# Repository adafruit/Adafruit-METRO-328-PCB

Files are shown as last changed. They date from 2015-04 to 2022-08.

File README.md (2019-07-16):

## Adafruit METRO 328 PCB

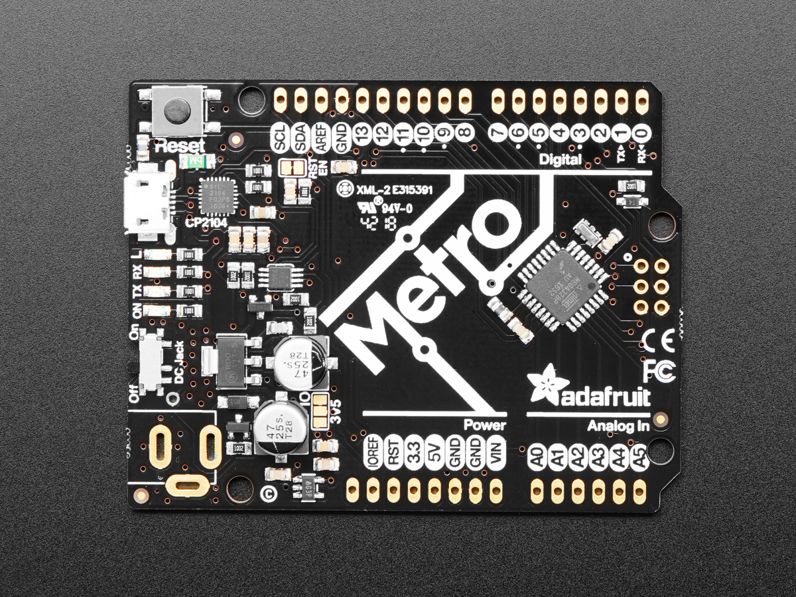
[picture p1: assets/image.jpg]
<a href="http://www.adafruit.com/products/2466"><br/>
Click here to purchase one from the Adafruit shop</a>

PCB files for the Adafruit METRO 328. Format is EagleCAD schematic and board layout

For more details, check out the product page at
* https://www.adafruit.com/products/2466

### Description

We sure love the ATmega328 here at Adafruit, and we use them a lot for our own projects. The processor has plenty of GPIO, Analog inputs, hardware UART SPI and I2C, timers and PWM galore - just enough for most simple projects. When we need to go small, we use a Metro Mini, but when size isn't as much of a concern, and a USB-serial converter is required, we reach for an Adafruit METRO.

METRO is the culmination of years of playing with AVRs: we wanted to make a development board that is easy to use and is hacker friendly.

ATmega328 brains - This popular chip has 32KB of flash (1/2 K is reserved for the bootloader), 2KB of RAM, clocked at 16MHz
Power the METRO with 7-9V polarity protected DC or the micro USB connector to any 5V USB source. The 2.1mm DC jack has an on/off switch next to it so you can turn off your setup easily. The METRO will automagically switch between USB and DC.
METRO has 20 GPIO pins, 6 of which are Analog in as well, and 2 of which are reserved for the USB-serial converter. There's also 6 PWMs available on 3 timers (1 x 16-bit, 2 x 8-bit). There's a hardware SPI port, hardware I2C port and hardware UART to USB.
GPIO Logic level is 5V but by cutting and soldering closed a jumper, you can easily convert it to 3.3V logic
USB to Serial converter, there's a hardware USB to Serial converter that can be used by any computer to listen/send data to the METRO, and can also be used to launch and update code via the bootloader
Four indicator LEDs, on the front edge of the PCB, for easy debugging. One green power LED, two RX/TX LEDs for the UART, and a red LED connected to pin PB5
Easy reprogramming, comes pre-loaded with the Optiboot bootloader, which is supported by avrdude and only uses 512 bytes.
Beautiful styling by PaintYourDragon and Bruce Yan, in Adafruit Black with gold plated pads.
Works with all Adafruit designed shields!
This version of the METRO 328 comes as a fully assembled and tested development board but without any headers or the DC jack attached. We do include these parts so that you can solder on if you like, or you can solder wires or header directly to the breakout pads. We also include 4 rubber bumpers to keep it from slipping off your desk.

### License

Adafruit invests time and resources providing this open source design, please support Adafruit and open-source hardware by purchasing products from [Adafruit](https://www.adafruit.com)!

Designed by Limor Fried/Ladyada for Adafruit Industries.

Creative Commons Attribution/Share-Alike. See license.txt for additional details.

Derivative of "Arduino UNO R3 Reference design" (http://www.arduino.cc/en/Main/ArduinoBoardUno)

All text above must be included in any redistribution

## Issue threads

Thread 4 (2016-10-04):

3D STEP file

rnamdos, 2016-10-04:
Can yall  provide a STEP file for this design for folks that don't have allegro? Thanks.

ladyada, 2016-10-04:
hiya
Format is EagleCAD schematic and board layout

Closed 2016-10-04.

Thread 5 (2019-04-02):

Mounting holes not making a perfect square

amm0nite, 2019-04-02:
Hello!
I noticed that the bottom right mounting hole (near A5 pin) is 0.085" from the right edge unlike all 3 other holes that are 0.075" from the edge of the board. I think it is weird that the mounting hole are not making a perfect square, Are my measurements correct?

Prizmagnetic, 2023-10-16:
Here's the measurements in Eagle, that one hole is definitely off

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

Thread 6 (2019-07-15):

Full Size METRO 328 Schematic is missing for CP2104 variant

sciguy14, 2019-07-15:
Hello Adafruit folks! It would appear that only the FTDI variant of the full size METRO board schematic is present in this repo. Would you be willing to add the schematic (in eagle and/or PDF format) for the newer variant with the the CP2104 chip that you are now shipping?

Thanks!

ladyada, 2019-07-16:
done!

sciguy14, 2019-07-16:
I have submitted a pull request with a readability cleanup to the schematic you shared :)
(No functional changes of course)
https://github.com/adafruit/Adafruit-METRO-328-PCB/pull/7

Closed 2019-07-16.

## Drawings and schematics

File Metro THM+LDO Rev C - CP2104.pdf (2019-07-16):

USB/Serial Bridge | POWER SUPPLY: 5V | POWER SUPPLY: 3.3V

## IO LEVEL SELECTION

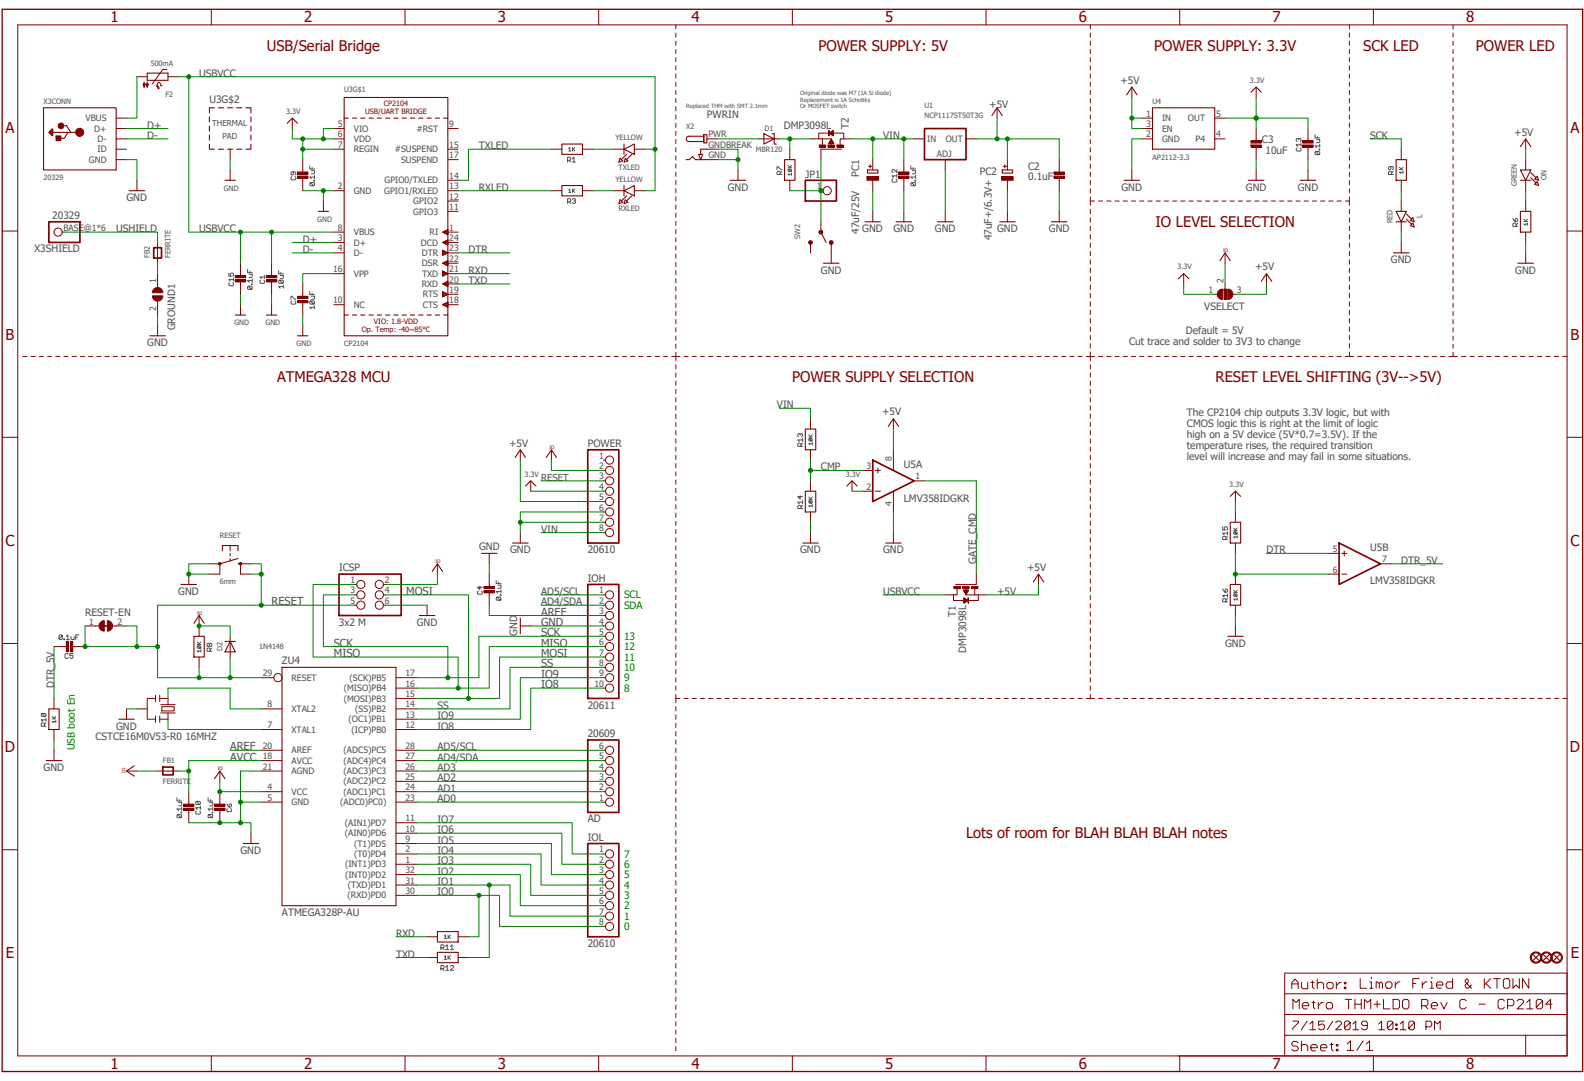
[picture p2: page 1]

SCK LED

Original diode was M7 (1A Si diode)
Replacement is 1A Schottky
DMP3098L

Cut trace and solder to 3V3 to change

The CP2104 chip outputs 3.3V logic, but with
CMOS logic this is right at the limit of logic
high on a 5V device (5V*0.7=3.5V). If the
temperature rises, the required transition
level will increase and may fail in some situations.

Lots of room for BLAH BLAH BLAH notes

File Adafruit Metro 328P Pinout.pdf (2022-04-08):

# Adafruit Metro 328P

# https://www.adafruit.com/products/2466

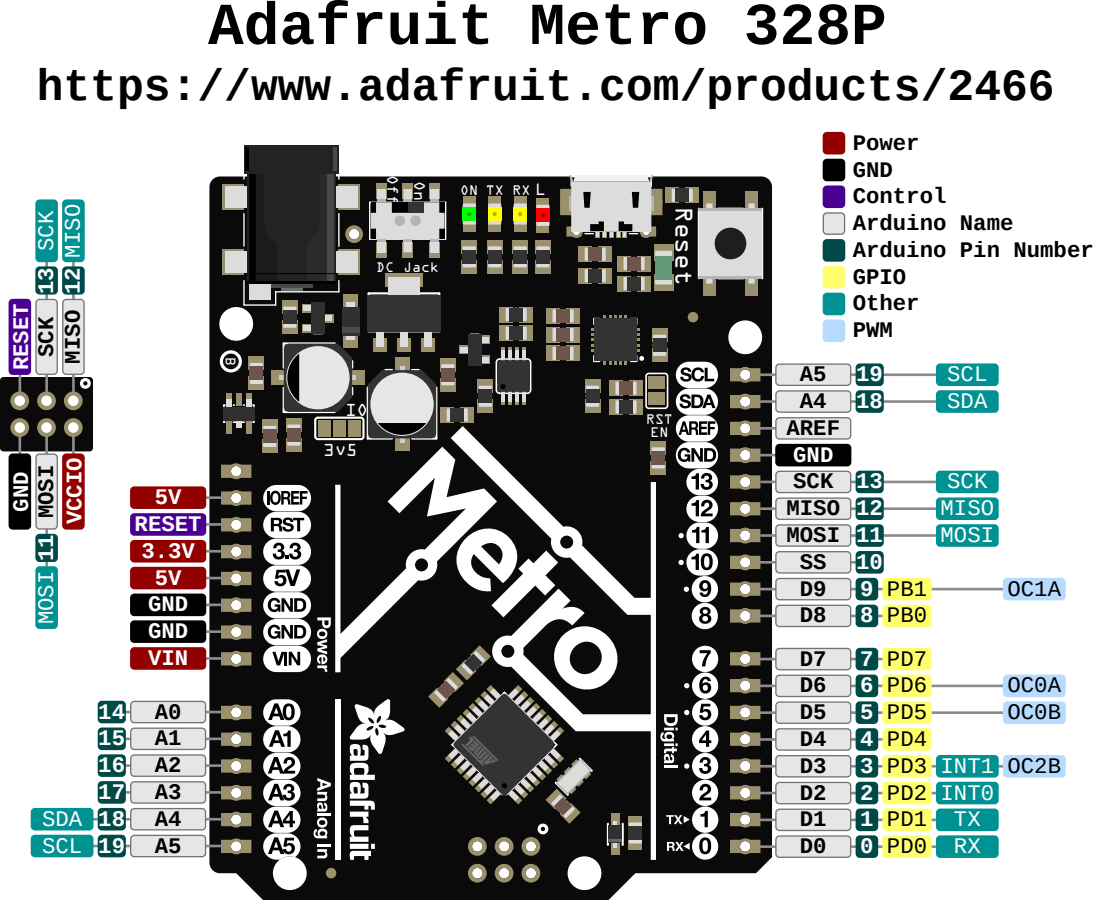
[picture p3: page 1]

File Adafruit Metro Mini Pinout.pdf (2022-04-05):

# Adafruit Metro Mini

# https://www.adafruit.com/products/2590

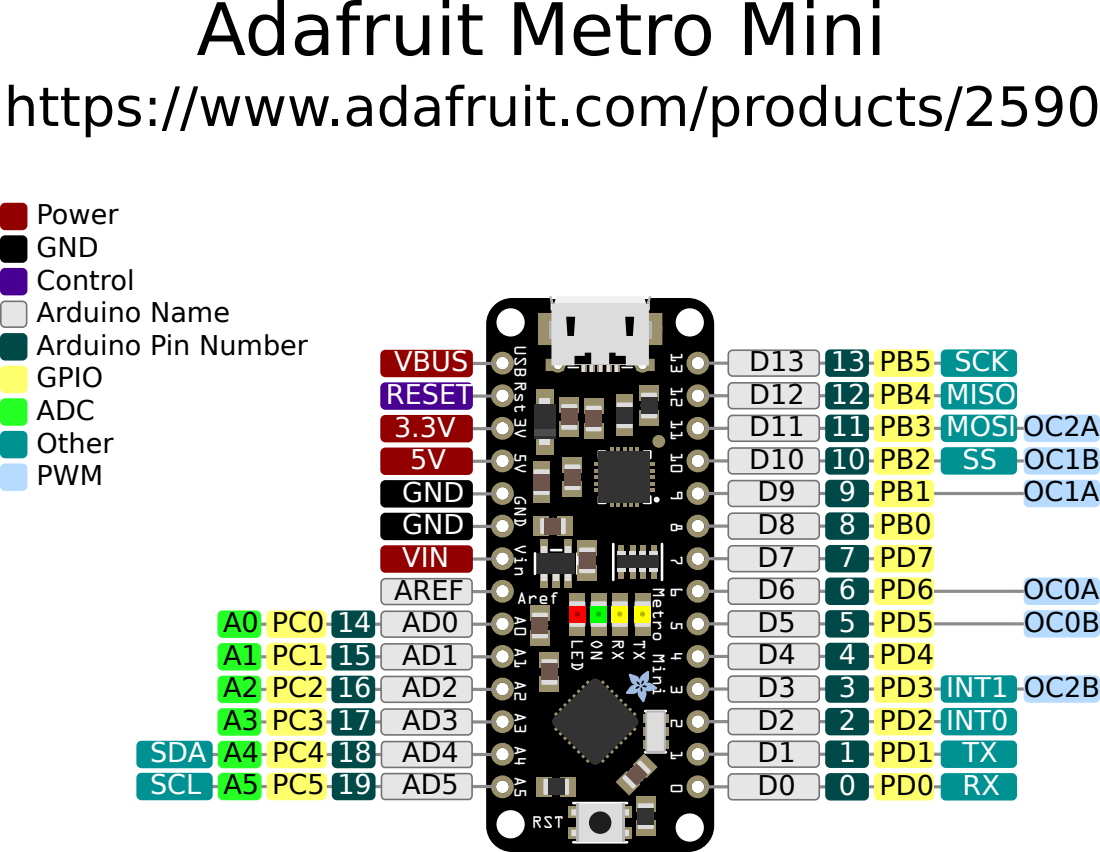
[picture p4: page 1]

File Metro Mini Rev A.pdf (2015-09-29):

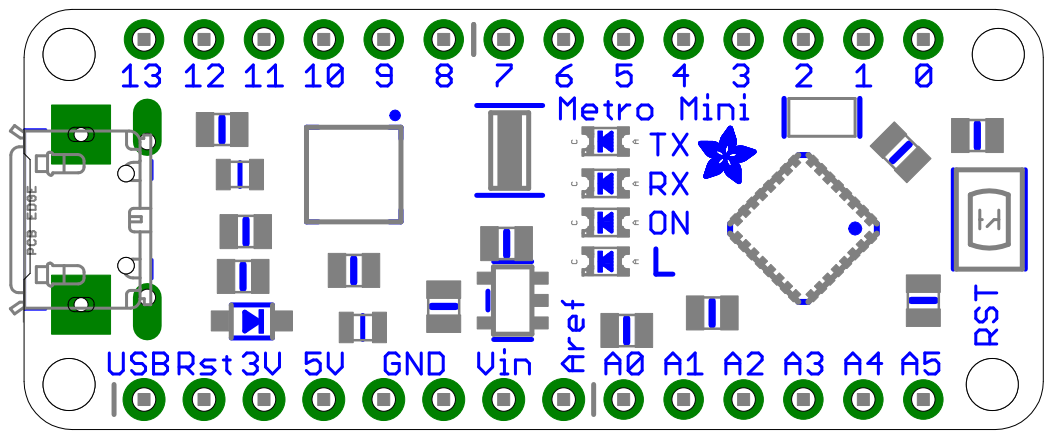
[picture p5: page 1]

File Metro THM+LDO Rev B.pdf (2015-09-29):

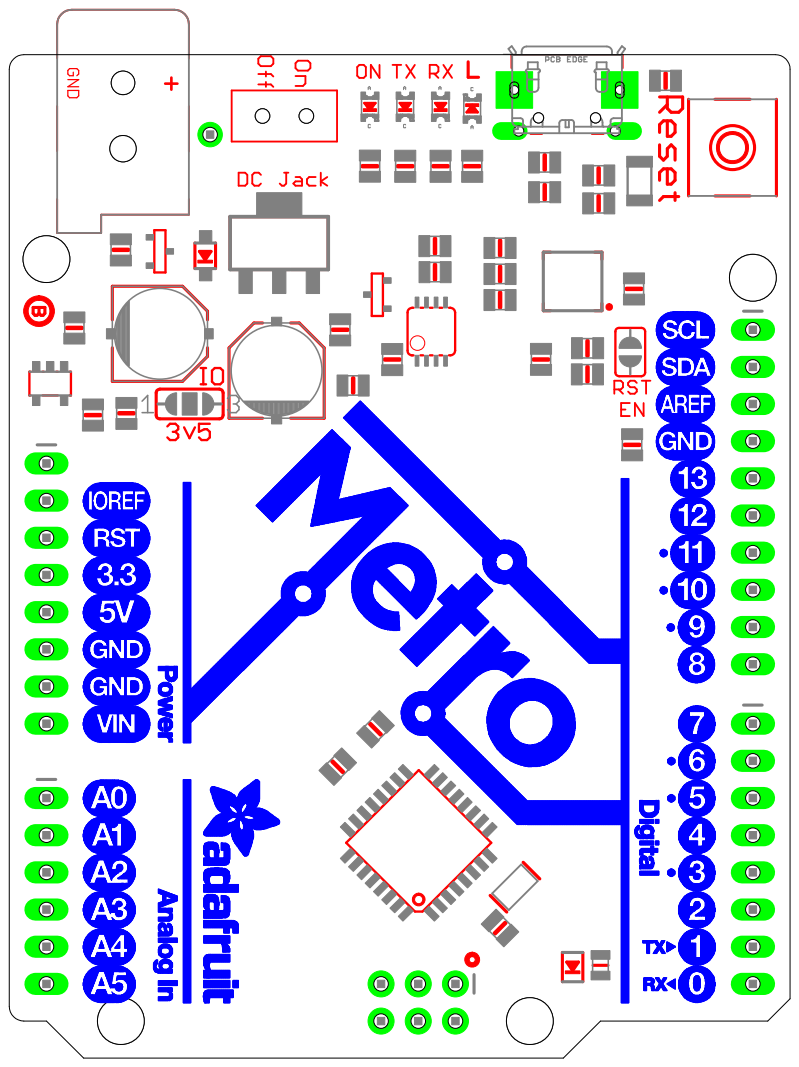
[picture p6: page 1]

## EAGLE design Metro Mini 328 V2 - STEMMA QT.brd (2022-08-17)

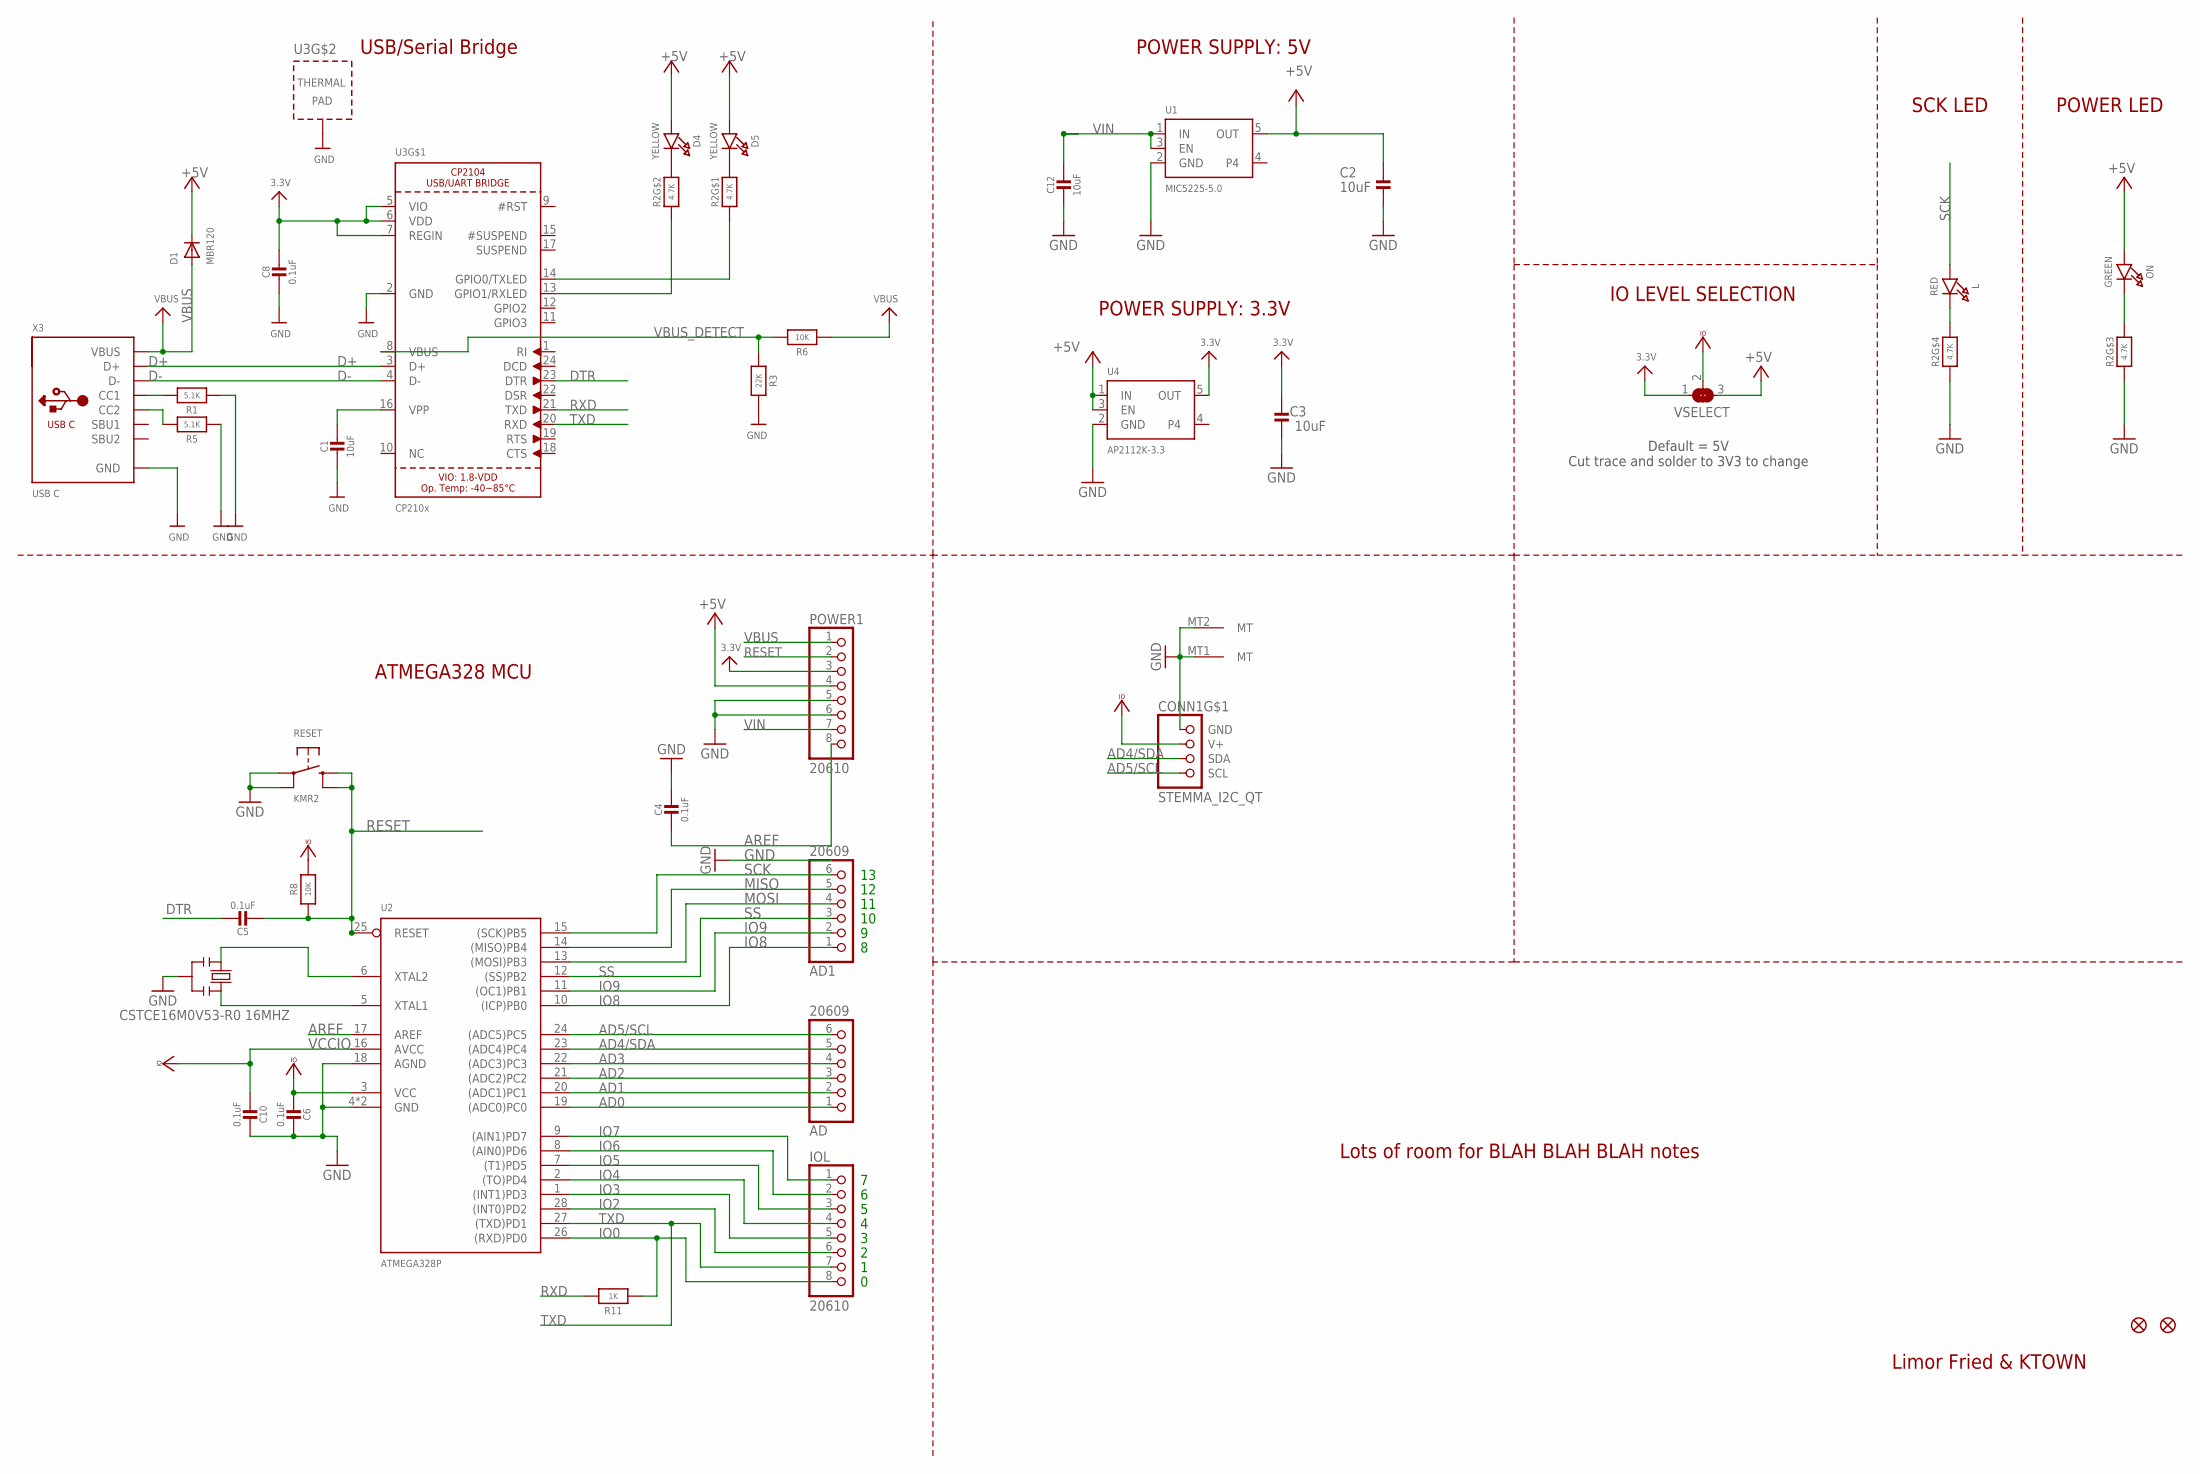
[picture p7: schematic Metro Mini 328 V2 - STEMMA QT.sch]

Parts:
AD, AD1: 20609; 1X06_ROUND
C1, C2, C3, C12: 10uF; 0805-NO
C4, C5, C6, C8, C10: 0.1uF; 0603-NO
CONN1: STEMMA_I2C_QT; JST_SH4
D1: MBR120; SOD-123FL
D4, D5: YELLOW; CHIPLED_0603_NOOUTLINE
FD1, FD2: FIDUCIAL_1MM
IOL: 20610; 1X08_ROUND
L: RED; CHIPLED_0603_NOOUTLINE
ON: GREEN; CHIPLED_0603_NOOUTLINE
POWER1: 20610; 1X08_ROUND_70
R1, R5: 5.1K; 0603-NO
R2: 4.7K; RESPACK_4X0603
R3: 22K; 0603-NO
R6, R8: 10K; 0603-NO
R11: 1K; 0603-NO
RESET: KMR2; BTN_KMR2_4.6X2.8
U1: MIC5225-5.0; SOT23-5
U2: ATMEGA328P; QFN28_4MM_.45MM
U3: CP210x; QFN24_4MM_SMSC
U4: AP2112K-3.3; SOT23-5
VSELECT: SOLDERJUMPER_2WAY; SOLDERJUMPER_2WAY_OPEN_NOPASTE
X3: USB C; USB_C_CUSB31-CFM2AX-01-X
Y2: CSTCE16M0V53-R0 16MHZ; RESONATOR

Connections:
3.3V: C3.2, C8.1, POWER1.3, U3.5 (VIO), U3.6 (VDD), U3.7 (REGIN), U4.5 (OUT), VSELECT.1
+5V: C2.2, D1.C, D4.A, D5.A, ON.A, POWER1.4, U1.5 (OUT), U4.1 (IN), U4.3 (EN), VSELECT.3
AD0: AD.1, U2.19 ((ADC0)PC0)
AD1: AD.2, U2.20 ((ADC1)PC1)
AD2: AD.3, U2.21 ((ADC2)PC2)
AD3: AD.4, U2.22 ((ADC3)PC3)
AD4/SDA: AD.5, CONN1.3 (SDA), U2.23 ((ADC4)PC4)
AD5/SCL: AD.6, CONN1.4 (SCL), U2.24 ((ADC5)PC5)
AREF: C4.2, POWER1.8, U2.17 (AREF)
D+: U3.3 (D+), X3.A6 (D+), X3.B6 (D+)
D-: U3.4 (D-), X3.A7 (D-), X3.B7 (D-)
DTR: C5.1, U3.23 (DTR)
GND: C1.2, C2.1, C3.1, C4.1, C6.1, C8.2, C10.1, C12.2, CONN1.1 (GND), CONN1.MT1 (MT), CONN1.MT2 (MT), POWER1.5, POWER1.6, R1.1, R2.3 (1), R2.4 (1), R3.1, R5.1, RESET.A, RESET.A' (P1), U1.2 (GND), U2.4 (GND), U2.18 (AGND), U2.29 (GND), U3.2 (GND), U3.THERM (TP), U4.2 (GND), X3.A1B12 (GND), X3.B1A12 (GND), Y2.2
IO0: IOL.8, R11.1, U2.26 ((RXD)PD0)
IO2: IOL.6, U2.28 ((INT0)PD2)
IO3: IOL.5, U2.1 ((INT1)PD3)
IO4: IOL.4, U2.2 ((TO)PD4)
IO5: IOL.3, U2.7 ((T1)PD5)
IO6: IOL.2, U2.8 ((AIN0)PD6)
IO7: IOL.1, U2.9 ((AIN1)PD7)
IO8: AD1.1, U2.10 ((ICP)PB0)
IO9: AD1.2, U2.11 ((OC1)PB1)
MISO: AD1.5, U2.14 ((MISO)PB4)
MOSI: AD1.4, U2.13 ((MOSI)PB3)
unnamed: L.C, R2.5 (2)
unnamed: ON.C, R2.6 (2)
unnamed: R2.1, U3.14 (GPIO0/TXLED)
unnamed: R1.2, X3.A5 (CC1)
unnamed: D4.C, R2.7 (2)
unnamed: D5.C, R2.8 (2)
unnamed: R5.2, X3.B5 (CC2)
unnamed: C1.1, U3.16 (VPP)
unnamed: R2.2 (1), U3.13 (GPIO1/RXLED)
RESET: C5.2, POWER1.2, R8.1, RESET.B (S), RESET.B' (S1), U2.25 (RESET)
RXD: R11.2, U3.21 (TXD)
SCK: AD1.6, L.A, U2.15 ((SCK)PB5)
SS: AD1.3, U2.12 ((SS)PB2)
TXD: IOL.7, U2.27 ((TXD)PD1), U3.20 (RXD)
VBUS: D1.A, POWER1.1, R6.2, X3.A4B9 (VBUS), X3.B4A9 (VBUS)
VBUS_DETECT: R3.2, R6.1, U3.8 (VBUS)
VCCIO: C6.2, C10.2, CONN1.2 (V+), R8.2, U2.3 (VCC), U2.16 (AVCC), VSELECT.2
VIN: C12.1, POWER1.7, U1.1 (IN), U1.3 (EN)
XTAL1: U2.5 (XTAL1), Y2.3
XTAL2: U2.6 (XTAL2), Y2.1

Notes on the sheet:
Limor Fried & KTOWN
POWER SUPPLY: 5V
USB/Serial Bridge
POWER SUPPLY: 3.3V
IO LEVEL SELECTION
POWER LED
ATMEGA328 MCU
SCK LED
Lots of room for BLAH BLAH BLAH notes
Default = 5V Cut trace and solder to 3V3 to change

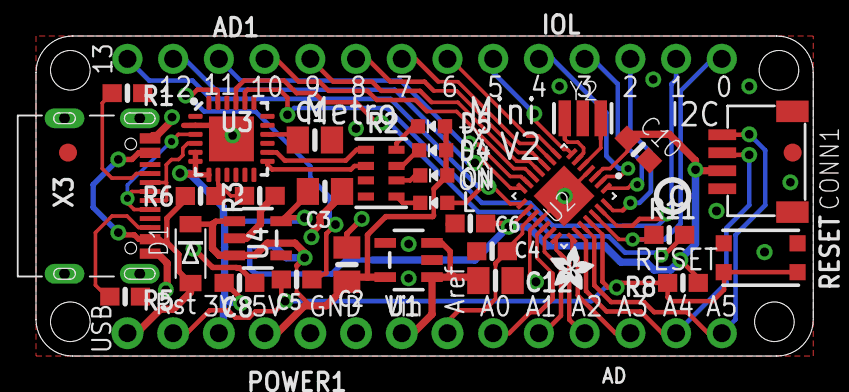
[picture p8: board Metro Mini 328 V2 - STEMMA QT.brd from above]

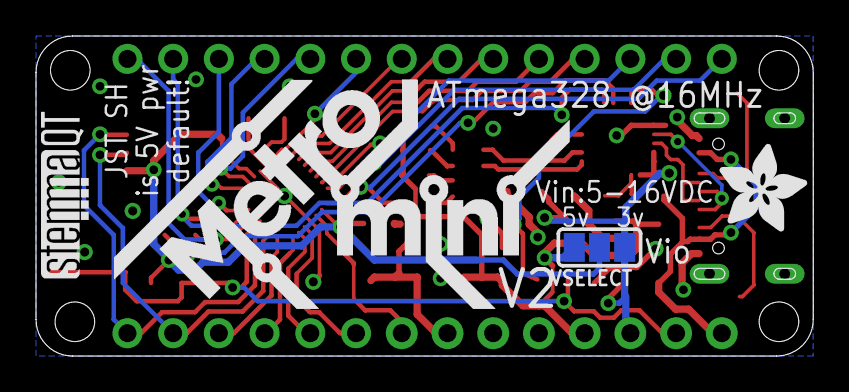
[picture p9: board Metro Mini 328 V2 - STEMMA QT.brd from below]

Board: 2 copper layers, 43.2 x 17.8 mm, 41 parts (4 on the bottom side), 44 nets.

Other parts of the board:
U$4: PCBFEAT-REV-040
U$5: ADAFRUIT_2.5MM
U$6: STEMMAQT
U$7: METROMINI_SILK
U$10: ADAFRUIT_5MM

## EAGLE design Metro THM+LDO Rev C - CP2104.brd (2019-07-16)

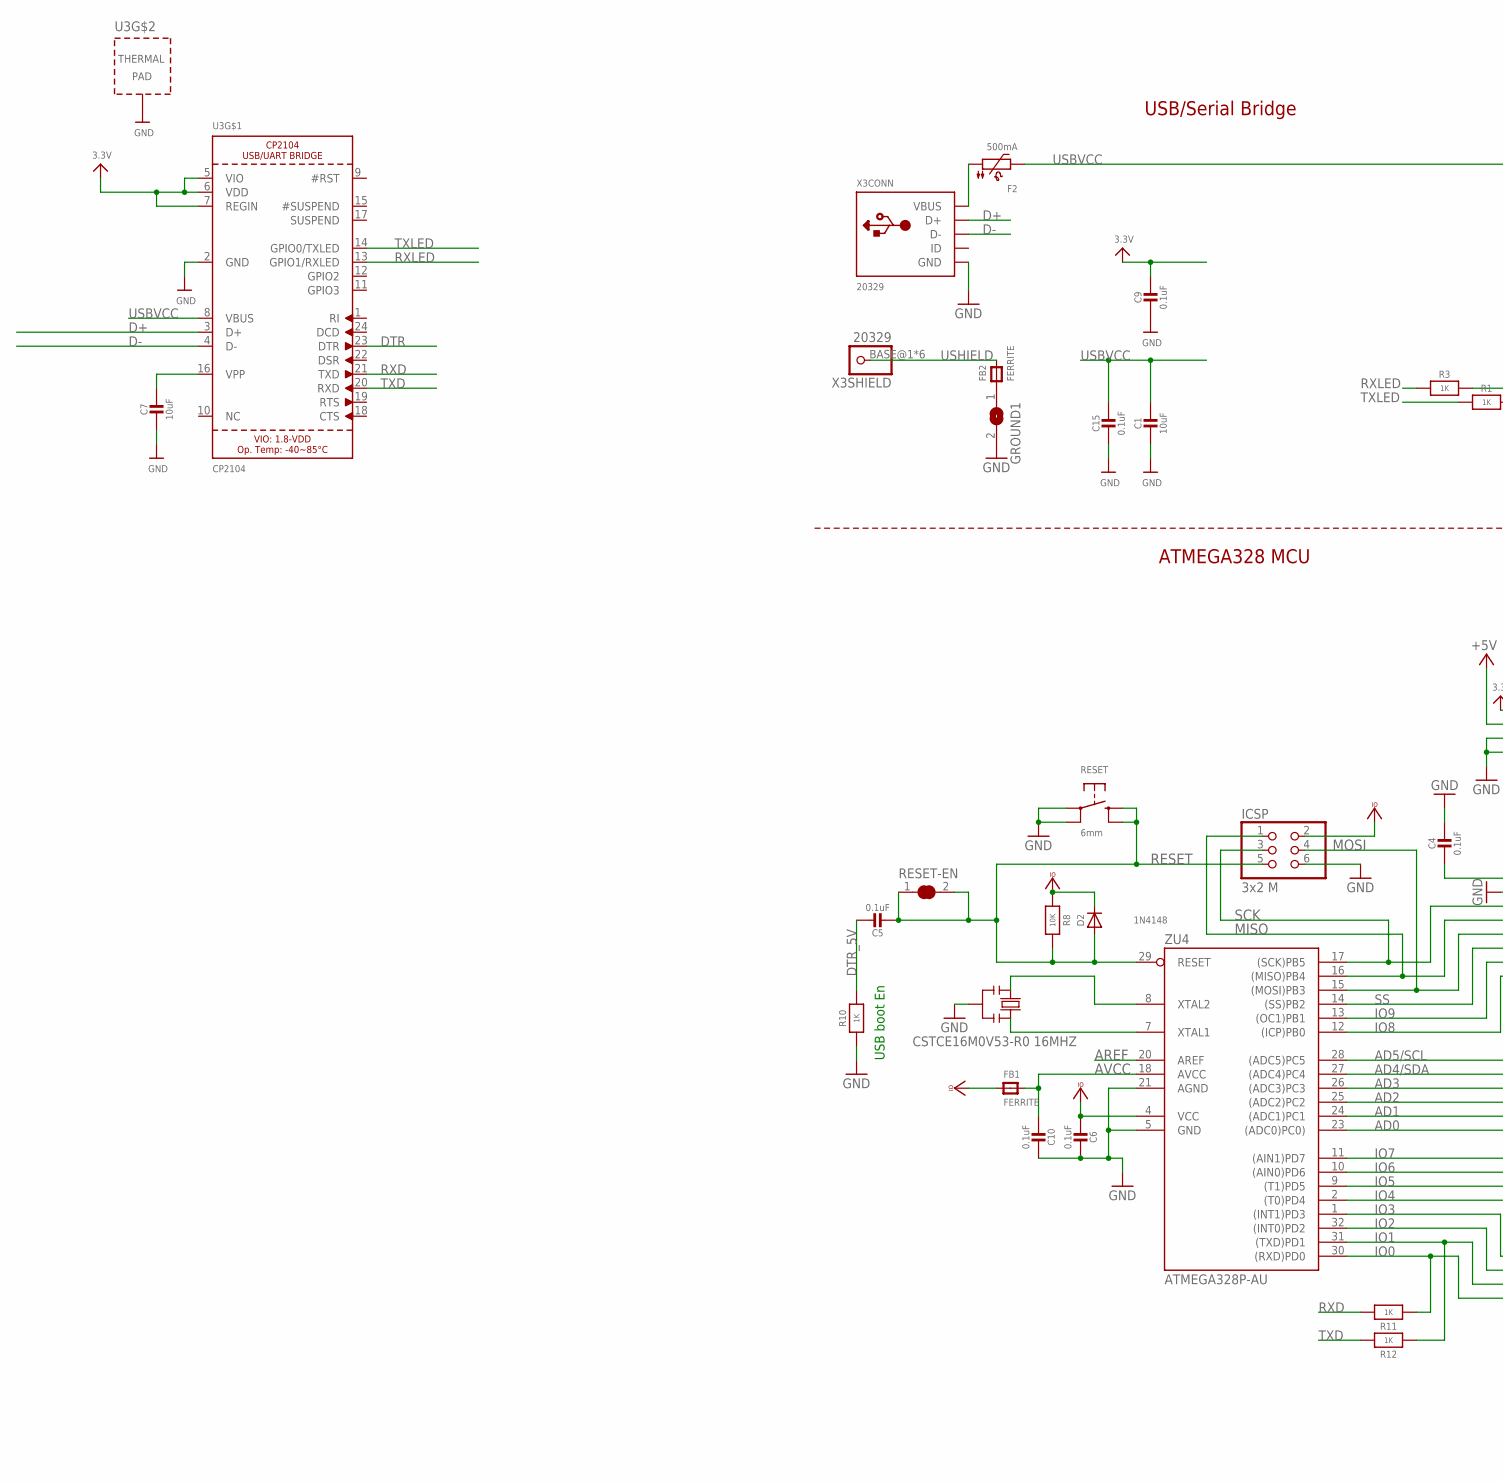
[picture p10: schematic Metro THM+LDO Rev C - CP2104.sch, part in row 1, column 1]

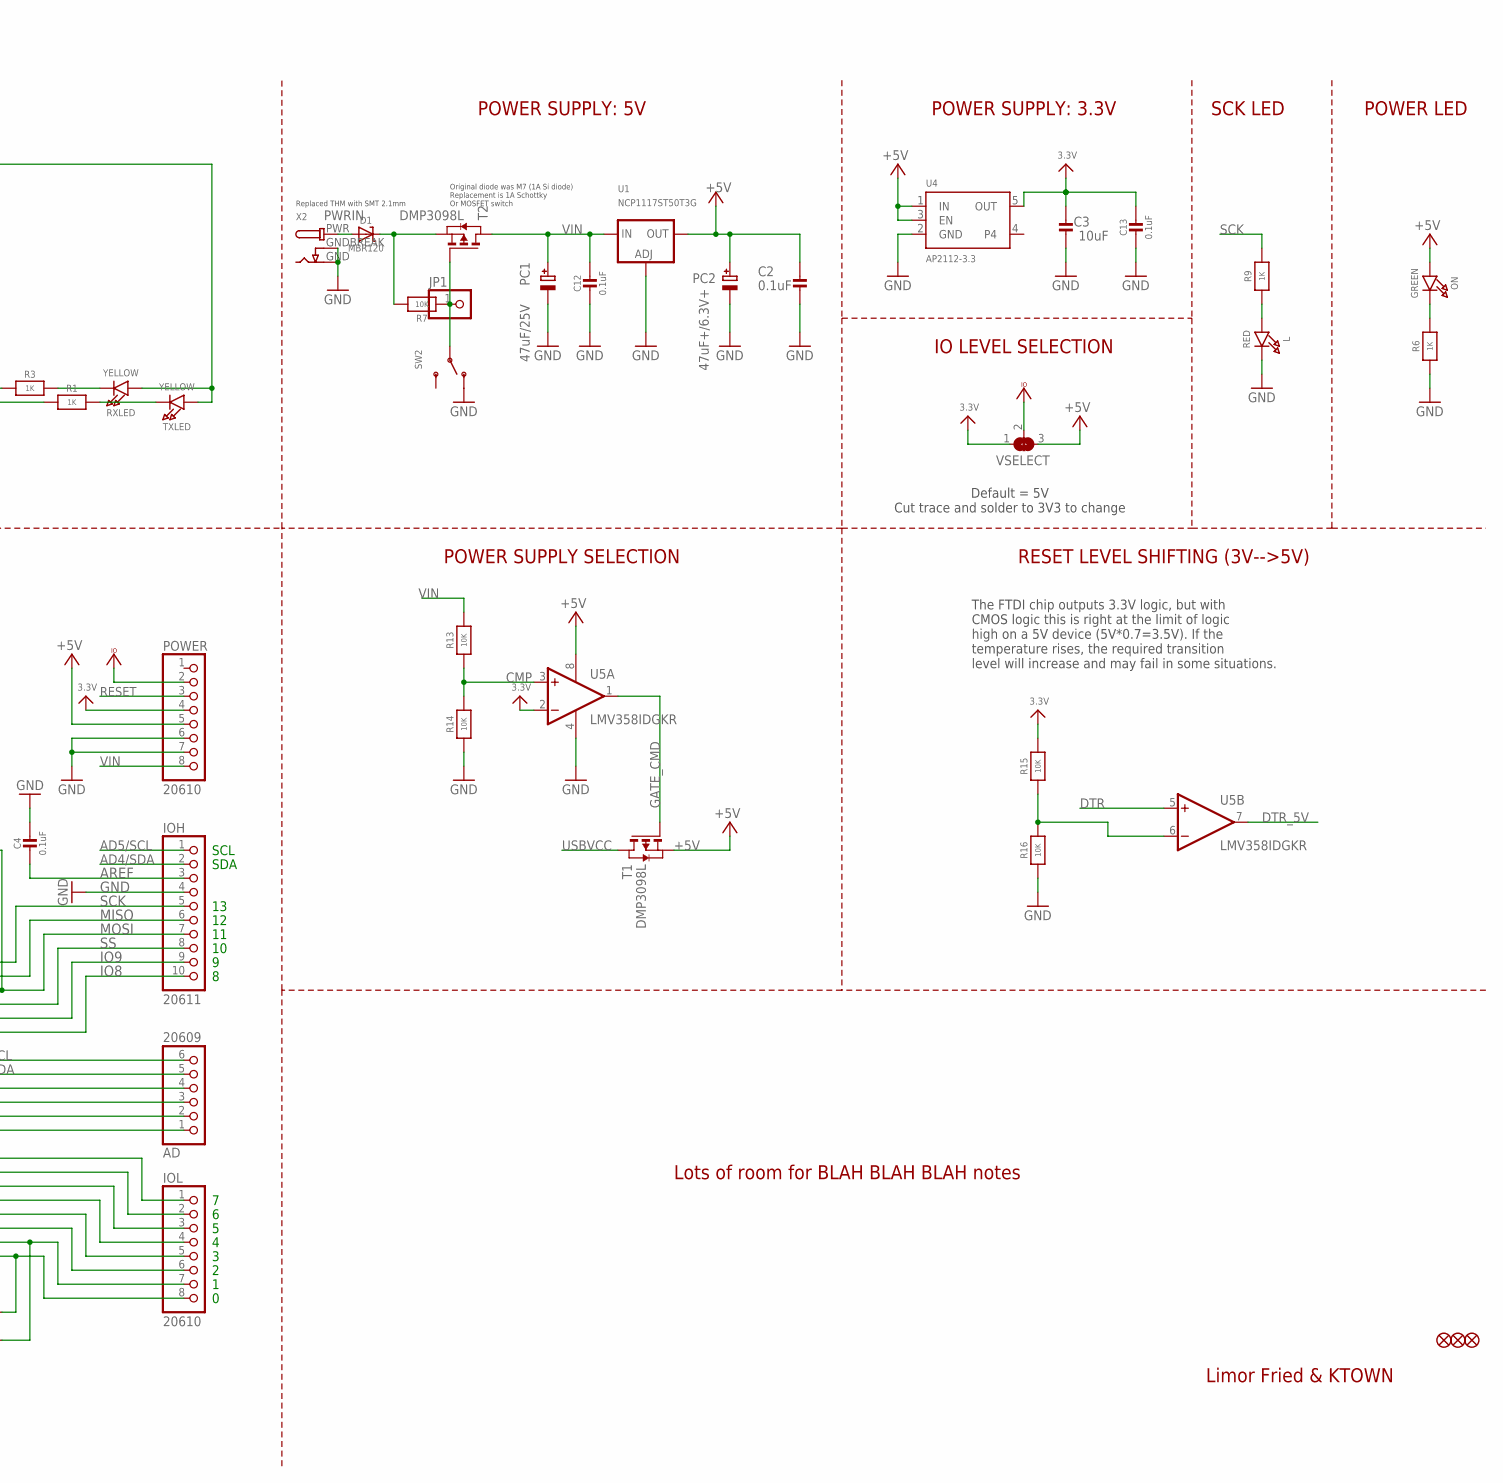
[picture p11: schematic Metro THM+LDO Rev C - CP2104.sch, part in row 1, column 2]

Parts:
AD: 20609; 1X06_OVAL
C1, C3, C7: 10uF; 0805-NO
C2, C4, C5, C6, C9, C12, C13, C15: 0.1uF; 0805-NO
C10: 0.1uF; 0805_10MGAP
D1: MBR120; SOD-123
D2: 1N4148; SOD-323
F2: 500mA; 1206-NO
FB1, FB2: FERRITE; 0805-NO
FD1, FD2, FD3: FIDUCIAL_1MM
GROUND1: SJ
ICSP: 3x2 M; 2X03_ROUND_70MIL
IOH: 20611; 1X10_OVAL
IOL: 20610; 1X08_OVAL
JP1: HEADER-1X1ROUND; 1X01_ROUND
L: RED; CHIPLED_0805_NOOUTLINE
ON: GREEN; CHIPLED_0805_NOOUTLINE
PC1: 47uF/25V; PANASONIC_D
PC2: 47uF+/6.3V+; PANASONIC_D
POWER: 20610; 1X08_OVAL
R1, R3, R6, R9, R10, R11, R12: 1K; 0805-NO
R7, R13, R14, R15, R16: 10K; 0805-NO
R8: 10K; _0805MP
RESET: 6mm; EVQ-Q2
RESET-EN: SOLDERJUMPER_CLOSED; SOLDERJUMPER_CLOSEDWIRE
RXLED: YELLOW; CHIPLED_0805_NOOUTLINE
SW2: SWITCH_SPDT; SPDT_SMT_SSSS811101
T1, T2: DMP3098L; SOT-23
TXLED: YELLOW; CHIPLED_0805_NOOUTLINE
U1: NCP1117ST50T3G; SOT223-R
U3: CP2104; QFN24_4MM_SMSC
U4: AP2112-3.3; SOT23-5
U5: LMV358IDGKR; MSOP08
VSELECT: SOLDERJUMPER_2WAY; SOLDERJUMPER_2WAY_OPEN_NOPASTE
X2: DCBARRELPTH; DCJACK_2MM_PTH
X3: 20329; 4UCONN_20329_V2
Y2: CSTCE16M0V53-R0 16MHZ; RESONATOR
ZU4: ATMEGA328P-AU; TQFP32-08

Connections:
3.3V: C3.2, C9.1, C13.1, POWER.4, R15.2, U3.5 (VIO), U3.6 (VDD), U3.7 (REGIN), U4.5 (OUT), U5.2 (-IN), VSELECT.1
+5V: C2.2, ON.A, PC2.+, POWER.5, T1.2 (S), U1.2 (OUT), U1.4 (OUT), U4.1 (IN), U4.3 (EN), U5.8 (V+), VSELECT.3
AD0: AD.1, ZU4.23 ((ADC0)PC0))
AD1: AD.2, ZU4.24 ((ADC1)PC1)
AD2: AD.3, ZU4.25 ((ADC2)PC2)
AD3: AD.4, ZU4.26 ((ADC3)PC3)
AD4/SDA: AD.5, IOH.2, ZU4.27 ((ADC4)PC4)
AD5/SCL: AD.6, IOH.1, ZU4.28 ((ADC5)PC5)
AREF: C4.2, IOH.3, ZU4.20 (AREF)
AVCC: C10.2, FB1.2, ZU4.18 (AVCC)
CMP: R13.1, R14.2, U5.3 (+IN)
D+: U3.3 (D+), X3.D+
D-: U3.4 (D-), X3.D-
DTR: U3.23 (DTR), U5.5 (+IN)
DTR_5V: C5.1, R10.2, U5.7 (OUT)
GATE_CMD: T1.3 (G), U5.1 (OUT)
GND: C1.2, C2.1, C3.1, C4.1, C6.1, C7.2, C9.2, C10.1, C12.2, C13.2, C15.2, GROUND1.2, ICSP.6, IOH.4, L.C, PC1.-, PC2.-, POWER.6, POWER.7, R6.1, R10.1, R14.1, R16.1, RESET.A, RESET.A' (P1), SW2.A (O), U1.1 (ADJ), U3.2 (GND), U3.THERM (TP), U4.2 (GND), U5.4 (V-), X2.GND, X2.GNDBREAK, X3.GND, Y2.2, ZU4.5 (GND), ZU4.21 (AGND)
IO0: IOL.8, R11.1, ZU4.30 ((RXD)PD0)
IO1: IOL.7, R12.1, ZU4.31 ((TXD)PD1)
IO2: IOL.6, ZU4.32 ((INT0)PD2)
IO3: IOL.5, ZU4.1 ((INT1)PD3)
IO4: IOL.4, ZU4.2 ((T0)PD4)
IO5: IOL.3, ZU4.9 ((T1)PD5)
IO6: IOL.2, ZU4.10 ((AIN0)PD6)
IO7: IOL.1, ZU4.11 ((AIN1)PD7)
IO8: IOH.10, ZU4.12 ((ICP)PB0)
IO9: IOH.9, ZU4.13 ((OC1)PB1)
MISO: ICSP.1, IOH.6, ZU4.16 ((MISO)PB4)
MOSI: ICSP.4, IOH.7, ZU4.15 ((MOSI)PB3)
unnamed: L.A, R9.1
unnamed: FB2.1, GROUND1.1
unnamed: ON.C, R6.2
unnamed: R3.1, RXLED.C
unnamed: R1.1, TXLED.C
unnamed: R15.1, R16.2, U5.6 (-IN)
unnamed: JP1.1, R7.1, SW2.B, T2.3 (G)
unnamed: D1.C, R7.2, T2.2 (S)
unnamed: C7.1, U3.16 (VPP)
PWRIN: D1.A, X2.PWR
RESET: C5.2, D2.A, ICSP.5, POWER.3, R8.1, RESET.B (S), RESET.B' (S1), RESET-EN.1, RESET-EN.2, ZU4.29 (RESET)
RXD: R11.2, U3.21 (TXD)
RXLED: R3.2, U3.13 (GPIO1/RXLED)
SCK: ICSP.3, IOH.5, R9.2, ZU4.17 ((SCK)PB5)
SS: IOH.8, ZU4.14 ((SS)PB2)
TXD: R12.2, U3.20 (RXD)
TXLED: R1.2, U3.14 (GPIO0/TXLED)
USBVCC: C1.1, C15.1, F2.2, RXLED.A, T1.1 (D), TXLED.A, U3.8 (VBUS)
USHIELD: FB2.2, X3.BASE@1 (1), X3.BASE@2 (1), X3.SPRT@1 (1), X3.SPRT@2 (1), X3.SPRT@3 (1), X3.SPRT@4 (1)
VBUS: F2.1, X3.VBUS
VCCIO: C6.2, D2.C, FB1.1, ICSP.2, POWER.2, R8.2, VSELECT.2, ZU4.4 (VCC)
VIN: C12.1, PC1.+, POWER.8, R13.2, T2.1 (D), U1.3 (IN)
XTAL1: Y2.3, ZU4.7 (XTAL1)
XTAL2: Y2.1, ZU4.8 (XTAL2)

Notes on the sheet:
USB boot En
SDA
SCL
Limor Fried & KTOWN
Original diode was M7 (1A Si diode) Replacement is 1A Schottky Or MOSFET switch
Replaced THM with SMT 2.1mm
POWER SUPPLY: 5V
USB/Serial Bridge
POWER SUPPLY: 3.3V
IO LEVEL SELECTION
POWER LED
ATMEGA328 MCU
POWER SUPPLY SELECTION
SCK LED
Lots of room for BLAH BLAH BLAH notes
Default = 5V Cut trace and solder to 3V3 to change
RESET LEVEL SHIFTING (3V-->5V)
The FTDI chip outputs 3.3V logic, but with CMOS logic this is right at the limit of logic high on a 5V device (5V*0.7=3.5V). If the temperature rises, the required transition level will increase and may fail in some situations.

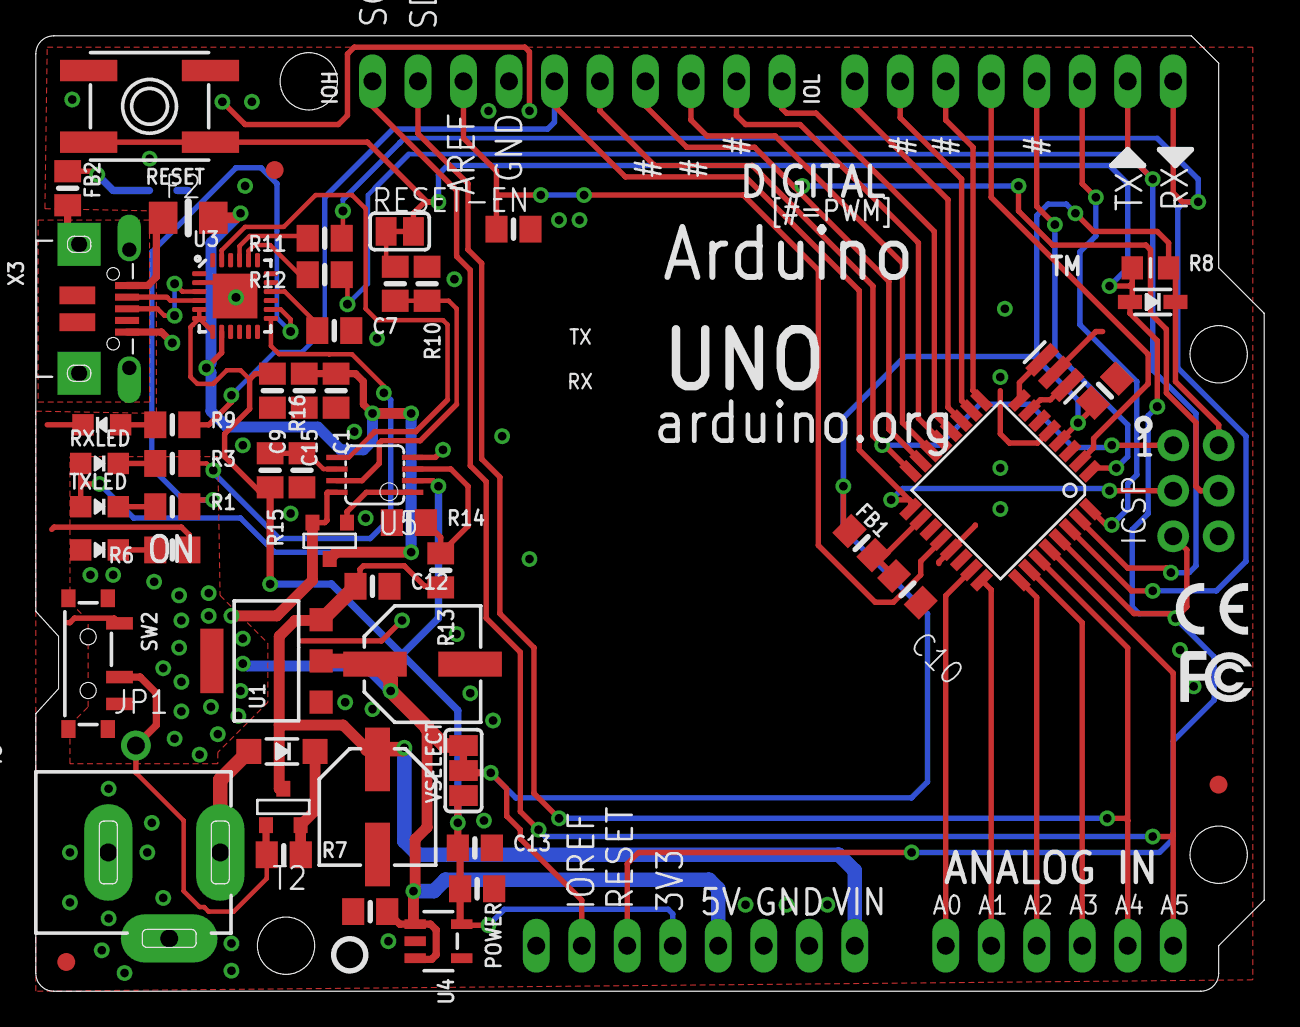
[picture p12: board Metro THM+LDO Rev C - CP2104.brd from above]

Board: 2 copper layers, 68.6 x 53.3 mm, 65 parts (1 on the bottom side), 53 nets.

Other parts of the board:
U$4: METROSILK_CP2104_TOP
U$14: METROSILK_BOT
U$15: PCBFEAT-REV-040
U$16: SYMBOL_FCC_TINY
U$17: SYMBOL_CE_TINY

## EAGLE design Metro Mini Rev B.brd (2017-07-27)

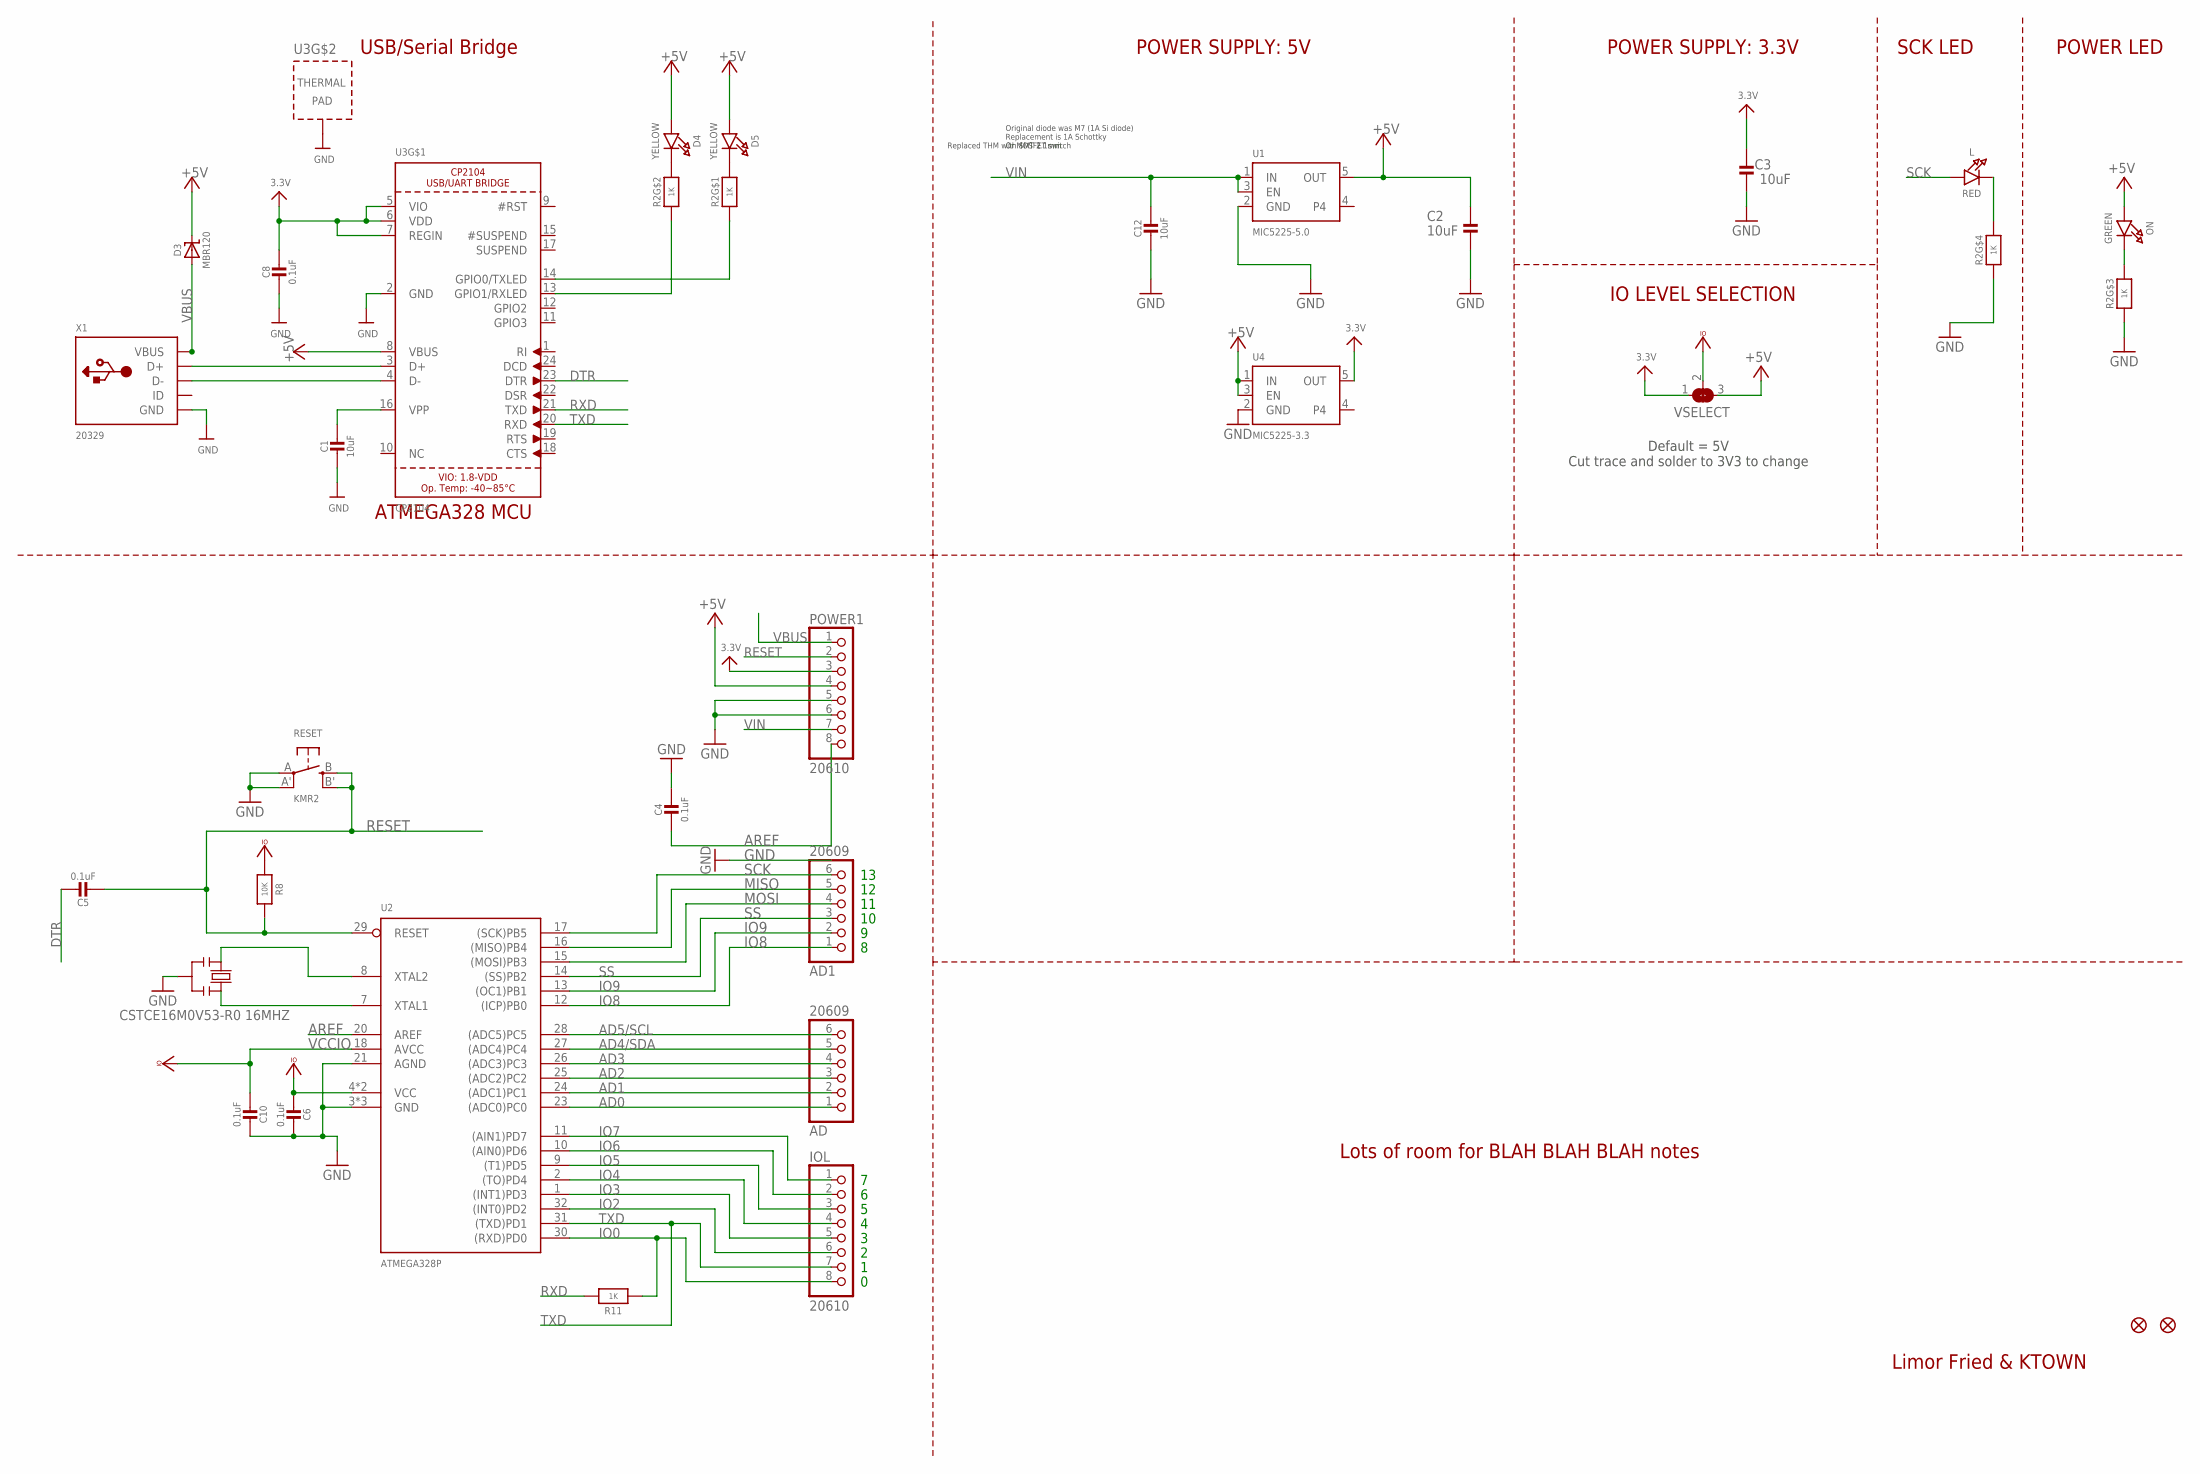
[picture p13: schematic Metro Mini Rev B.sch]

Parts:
AD, AD1: 20609; 1X06_ROUND
C1, C2, C3, C12: 10uF; 0805-NO
C4, C6, C8, C10: 0.1uF; 0805-NO
C5: 0.1uF; _0805MP
D3: MBR120; SOD-123
D4, D5: YELLOW; CHIPLED_0805_NOOUTLINE
FD1, FD2: FIDUCIAL""; FIDUCIAL_1MM
IOL: 20610; 1X08_ROUND
L: RED; CHIPLED_0805_NOOUTLINE
ON: GREEN; CHIPLED_0805_NOOUTLINE
POWER1: 20610; 1X08_ROUND_70
R2: 1K; RESPACK_4X0603
R8: 10K; 0805-NO
R11: 1K; 0805-NO
RESET: KMR2; BTN_KMR2_4.6X2.8
U1: MIC5225-5.0; SOT23-5
U2: ATMEGA328P; MLF32-TH
U3: CP2104; QFN24_4MM_SMSC
U4: MIC5225-3.3; SOT23-5
VSELECT: SOLDERJUMPER_2WAY; SOLDERJUMPER_2WAY_OPEN_NOPASTE
X1: 20329; 4UCONN_20329_V2
Y2: CSTCE16M0V53-R0 16MHZ; RESONATOR

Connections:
3.3V: C3.2, C8.1, POWER1.3, U3.5 (VIO), U3.6 (VDD), U3.7 (REGIN), U4.5 (OUT), VSELECT.1
+5V: C2.2, D3.C, D4.A, D5.A, ON.A, POWER1.4, U1.5 (OUT), U3.8 (VBUS), U4.1 (IN), U4.3 (EN), VSELECT.3
AD0: AD.1, U2.23 ((ADC0)PC0)
AD1: AD.2, U2.24 ((ADC1)PC1)
AD2: AD.3, U2.25 ((ADC2)PC2)
AD3: AD.4, U2.26 ((ADC3)PC3)
AD4/SDA: AD.5, U2.27 ((ADC4)PC4)
AD5/SCL: AD.6, U2.28 ((ADC5)PC5)
AREF: C4.2, POWER1.8, U2.20 (AREF)
DTR: C5.1, U3.23 (DTR)
GND: C1.2, C2.1, C3.1, C4.1, C6.1, C8.2, C10.1, C12.2, POWER1.5, POWER1.6, R2.3 (1), R2.4 (1), RESET.A, RESET.A' (P1), U1.2 (GND), U2.3 (GND), U2.5 (GND), U2.21 (AGND), U2.TH (GND), U3.2 (GND), U3.THERM (TP), U4.2 (GND), X1.BASE@1 (GND), X1.BASE@2 (GND), X1.GND, X1.SPRT@1 (GND), X1.SPRT@2 (GND), X1.SPRT@3 (GND), X1.SPRT@4 (GND), Y2.2
IO0: IOL.8, R11.1, U2.30 ((RXD)PD0)
IO2: IOL.6, U2.32 ((INT0)PD2)
IO3: IOL.5, U2.1 ((INT1)PD3)
IO4: IOL.4, U2.2 ((TO)PD4)
IO5: IOL.3, U2.9 ((T1)PD5)
IO6: IOL.2, U2.10 ((AIN0)PD6)
IO7: IOL.1, U2.11 ((AIN1)PD7)
IO8: AD1.1, U2.12 ((ICP)PB0)
IO9: AD1.2, U2.13 ((OC1)PB1)
MISO: AD1.5, U2.16 ((MISO)PB4)
MOSI: AD1.4, U2.15 ((MOSI)PB3)
unnamed: L.C, R2.5 (2)
unnamed: ON.C, R2.6 (2)
unnamed: R2.1, U3.14 (GPIO0/TXLED)
unnamed: D4.C, R2.7 (2)
unnamed: D5.C, R2.8 (2)
unnamed: U3.3 (D+), X1.D+
unnamed: U3.4 (D-), X1.D-
unnamed: C1.1, U3.16 (VPP)
unnamed: R2.2 (1), U3.13 (GPIO1/RXLED)
RESET: C5.2, POWER1.2, R8.1, RESET.B (S), RESET.B' (S1), U2.29 (RESET)
RXD: R11.2, U3.21 (TXD)
SCK: AD1.6, L.A, U2.17 ((SCK)PB5)
SS: AD1.3, U2.14 ((SS)PB2)
TXD: IOL.7, U2.31 ((TXD)PD1), U3.20 (RXD)
VBUS: D3.A, POWER1.1, X1.VBUS
VCCIO: C6.2, C10.2, R8.2, U2.4 (VCC), U2.6 (VCC), U2.18 (AVCC), VSELECT.2
VIN: C12.1, POWER1.7, U1.1 (IN), U1.3 (EN)
XTAL1: U2.7 (XTAL1), Y2.3
XTAL2: U2.8 (XTAL2), Y2.1

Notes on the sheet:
Limor Fried & KTOWN
Original diode was M7 (1A Si diode) Replacement is 1A Schottky Or MOSFET switch
Replaced THM with SMT 2.1mm
POWER SUPPLY: 5V
USB/Serial Bridge
POWER SUPPLY: 3.3V
IO LEVEL SELECTION
POWER LED
ATMEGA328 MCU
SCK LED
Lots of room for BLAH BLAH BLAH notes
Default = 5V Cut trace and solder to 3V3 to change

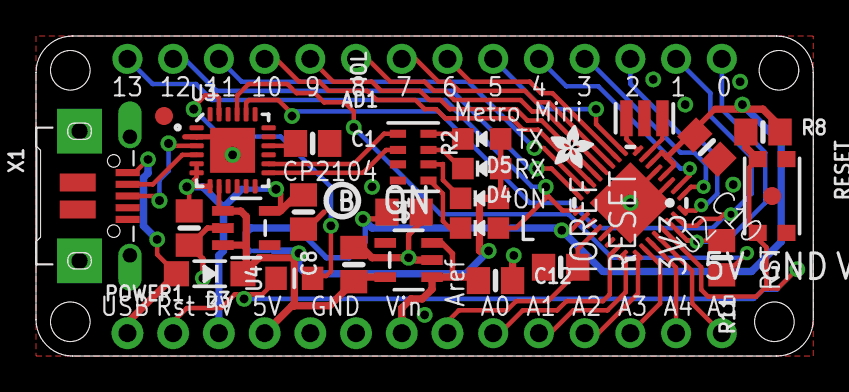
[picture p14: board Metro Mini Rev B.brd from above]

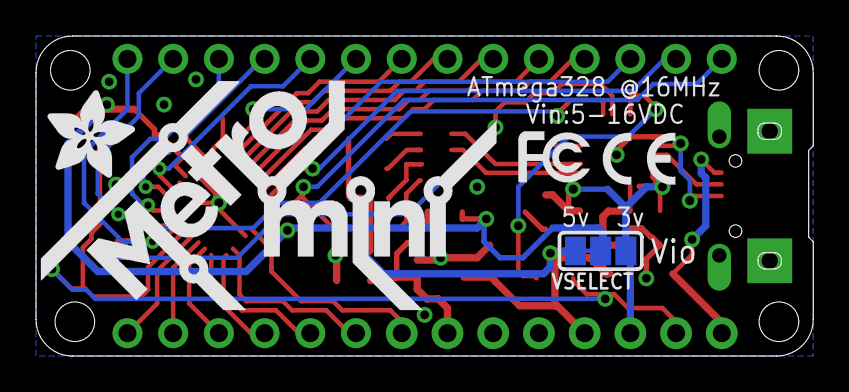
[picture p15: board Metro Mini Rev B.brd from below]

Board: 2 copper layers, 43.2 x 17.8 mm, 37 parts (5 on the bottom side), 41 nets.

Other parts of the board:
U$4: PCBFEAT-REV-040
U$5: ADAFRUIT_2.5MM
U$7: METROMINI_SILK
U$10: ADAFRUIT_5MM
U$12: SYMBOL_CE_TINY
U$14: SYMBOL_FCC_TINY

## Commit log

2015-04-28 choo choo here comes METRO!
    [Metro THM+LDO Rev B.brd, Metro THM+LDO Rev B.sch]
2015-09-27 PDF Board Pin Outs
    Thought I would learn the basics of Eagle Cad and create some pinout
    diagrams for the Metro Boards.
2019-07-16 add cp2104 version
    [Metro THM+LDO Rev C - CP2104.brd, Metro THM+LDO Rev C - CP2104.sch]
2019-07-16 Readability Improvements to Metro RevC Schematic
    Moved CP2104 from off-page into USB/Serial section of schematic.
    Changed Reset Level Shifting note to correctly refer to the CP2104 instead of the old FTDI chip.
    Moved some things arround slightly to reduce text overlaps.
    Adjusted net routing around CP2104 to improve clarity.
    Added PDF Export for Metro Rev C Schematic.
    [Metro THM+LDO Rev C - CP2104.sch]
2022-08-17 Add Mini V2 board files.
    [Metro Mini 328 V2 - STEMMA QT.brd, Metro Mini 328 V2 - STEMMA QT.sch]

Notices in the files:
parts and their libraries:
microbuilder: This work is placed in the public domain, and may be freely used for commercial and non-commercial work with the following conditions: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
